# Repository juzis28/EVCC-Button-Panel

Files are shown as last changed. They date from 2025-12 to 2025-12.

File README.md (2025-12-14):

# KEBA EVCC Panel - ESP32 Control System





ESP32-based control panel for managing **EVCC** (Electric Vehicle Charge Controller) charging modes through **Home Assistant**. Physical buttons with LED indicators allow easy mode switching, while a separate status LED panel shows system health.

## ⚠️ Disclaimer

**This project is for personal use and educational purposes only.**

The author assumes no responsibility for any damage, malfunction, or issues arising from the use of this project. Use at your own risk. This documentation is provided "as is" for informational purposes only. Always consult qualified professionals when working with electrical systems and EV charging equipment.

### 🔄 Bidirectional Synchronization

The panel is **fully synchronized** with EVCC and Home Assistant - changes work **in both directions**:
- Press a physical button → EVCC mode changes → Home Assistant updates
- Change mode in Home Assistant → EVCC updates → Panel LED reflects new mode
- Change mode in EVCC web UI → Home Assistant syncs → Panel LED updates automatically

This ensures the panel always shows the **current active mode**, regardless of where the change was initiated.

## 🎯 Project Background

This project was developed for personal use with the following setup:

**EV Charging Station:**
- **KEBA KeContact P30 x-series** wallbox
- Part of **SolarEdge** ecosystem (with SolarEdge inverter)
- Should also be compatible with other original or rebranded KEBA P30 x-series charging stations

**Software Stack:**
| Component | Platform |
|---|---|
| **EVCC** | Proxmox LXC Container |
| **Home Assistant** | Proxmox Virtual Machine |
| **EVCC Integration** | Home Assistant HACS |
| **ESPHome** | Proxmox LXC Container (or local installation) |

## ✨ Features

| Feature | Description |
|---|---|
| **4 Charging Modes** | OFF, SOLAR (PV), MIN+PV, FAST (NOW) |
| **Physical Buttons** | Momentary buttons with integrated LED indicators |
| **Status LED Panel** | 4-LED panel (D1-D4) showing Power, HA, WiFi, EVCC status |
| **Bidirectional Sync** | Panel ↔ Home Assistant ↔ EVCC fully synchronized |
| **Error Mode** | All LEDs blink when WiFi/HA connection lost |
| **5s Restart** | Hold OFF button for 5 seconds to restart ESP32 |
| **Night Mode** | Disable button LEDs via Home Assistant boolean |
| **Multi-Press Protection** | Prevents conflicts from simultaneous button presses |

## 🔧 Hardware

### Assembled Project

The panel features a **3D printed enclosure** mounted on top of the KEBA KeContact P30 charger:

<p align="center">
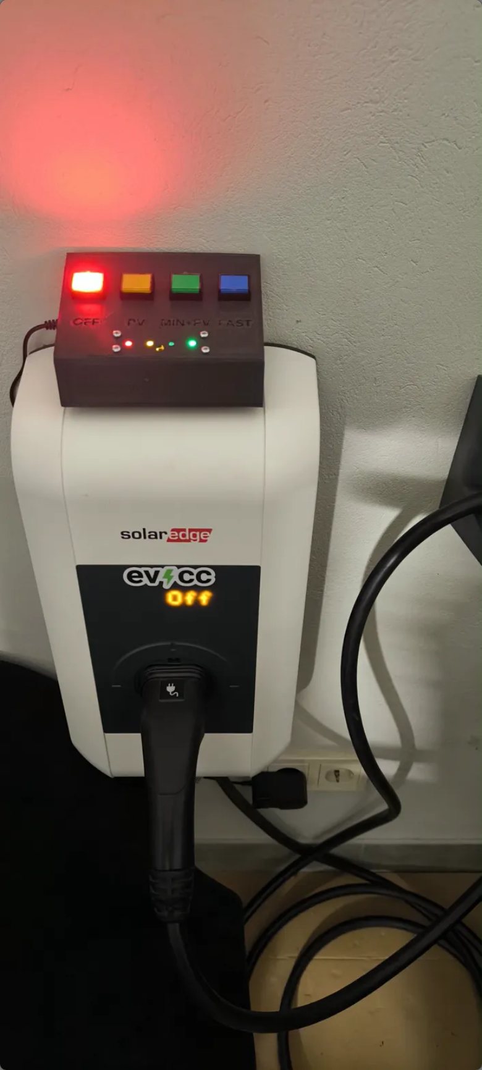
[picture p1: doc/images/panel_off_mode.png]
OFF Mode
  
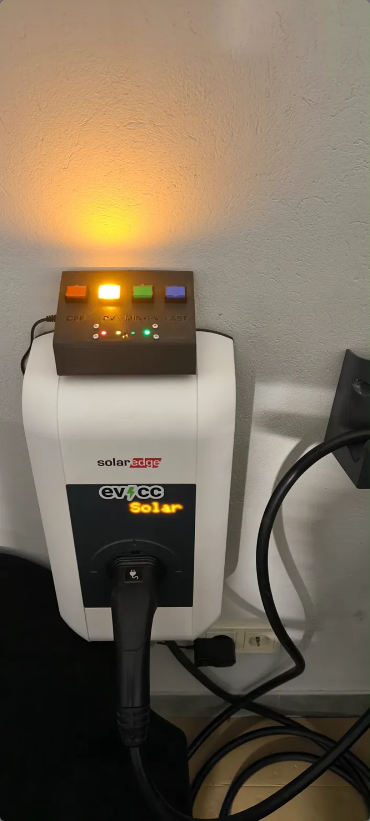
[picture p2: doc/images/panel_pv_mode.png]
PV Mode
  
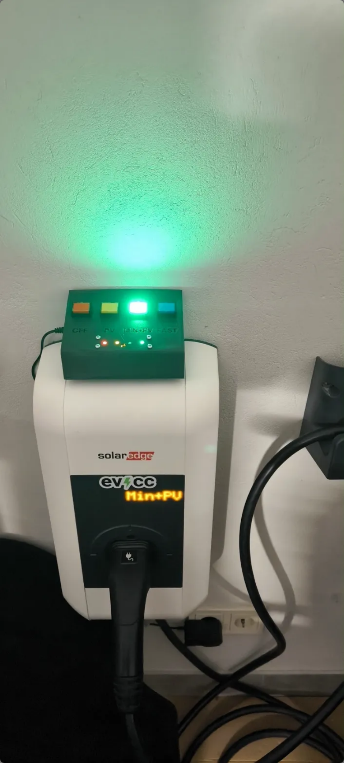
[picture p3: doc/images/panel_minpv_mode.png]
MIN+PV Mode
  
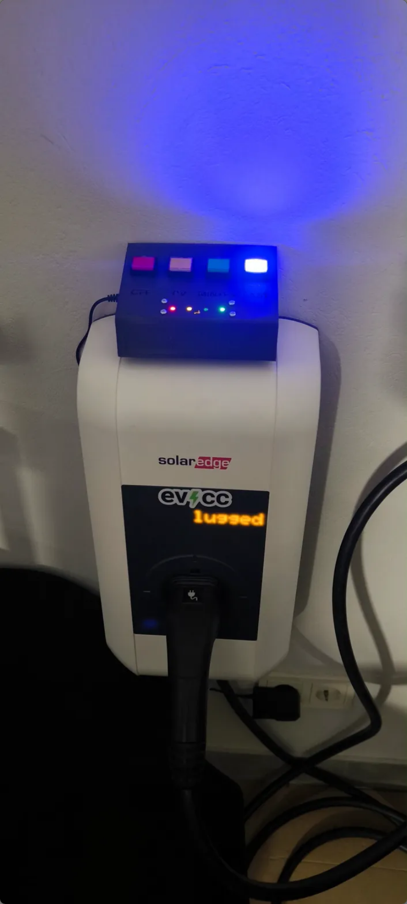
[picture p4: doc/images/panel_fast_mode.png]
FAST Mode
    
</p>

**Visible elements:**
- 4 LED push buttons (OFF, PV, MIN+PV, FAST) with mode labels
- Status LED panel (D1-D4) showing Power, HA, WiFi, EVCC status
- 3D printed enclosure with integrated cable management
- KEBA KeContact P30 x-series charger (SolarEdge branded)

### Main Components

| Component | Description | Link |
|---|---|---|
| **ESP32 Board** | ESP32_Relay_X4_V1.1 (LC Technology) | [AliExpress](https://www.aliexpress.com/item/1005008762604101.html) |
| **LED Buttons** | 12V LED Momentary Push Buttons AL6-M (4 colors) (COM-NO contacts required) | [AliExpress](https://www.aliexpress.com/item/1005007250758674.html) |
| **Status LED Panel** | ST-009 4-Bit Indicator Light Module (DC 3.3-5V) | [AliExpress](https://www.aliexpress.com/item/1005009691105445.html) |
| **DC Power Socket** | 5.5mm x 2.5mm Female Panel Mount Connector | [AliExpress](https://www.aliexpress.com/item/1005006755624202.html) |
| **Power Supply** | 12V 2A AC/DC Adapter (5.5mm x 2.5mm plug) | [AliExpress](https://www.aliexpress.com/item/1005007286854242.html) |

### Component Photos

<p align="center">
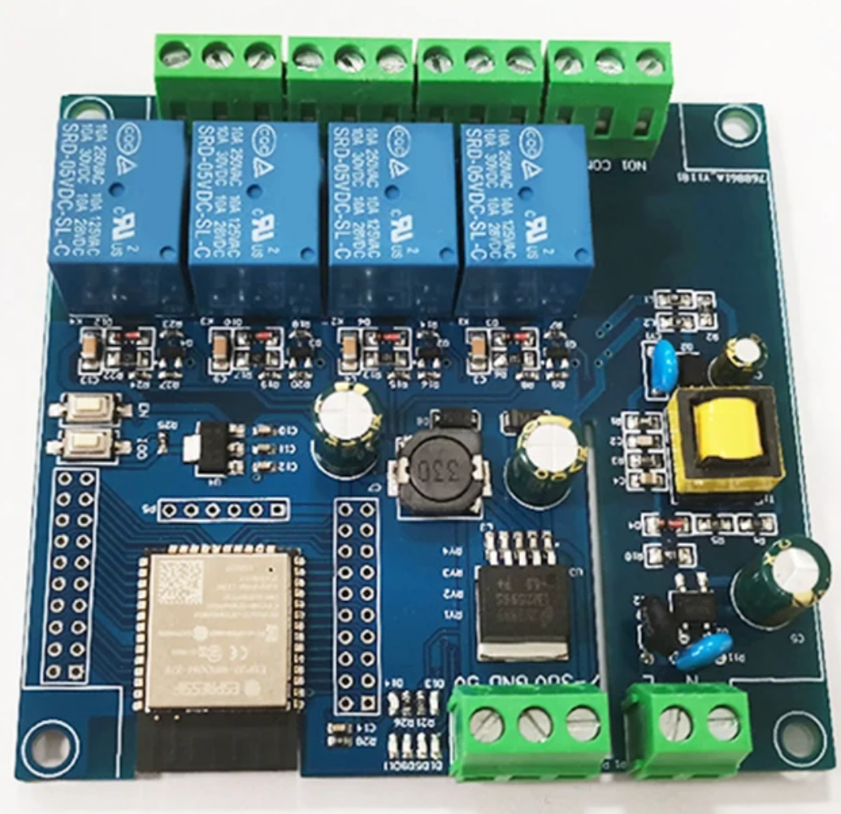
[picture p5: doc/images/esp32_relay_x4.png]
ESP32 Relay X4 Board
  
  <br><em>ESP32_Relay_X4_V1.1 Board</em>
</p>

<p align="center">
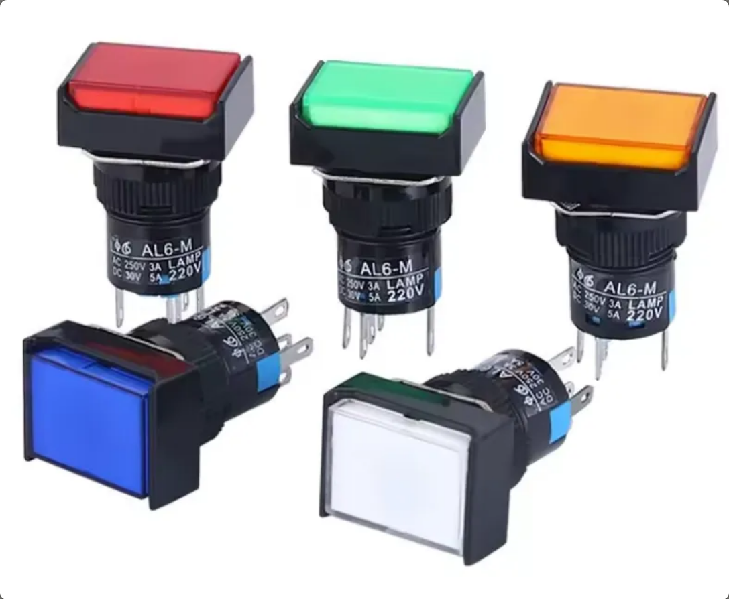
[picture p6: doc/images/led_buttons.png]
LED Push Buttons
  
  <br><em>12V LED Momentary Push Buttons (AL6-M)</em>
</p>

<p align="center">
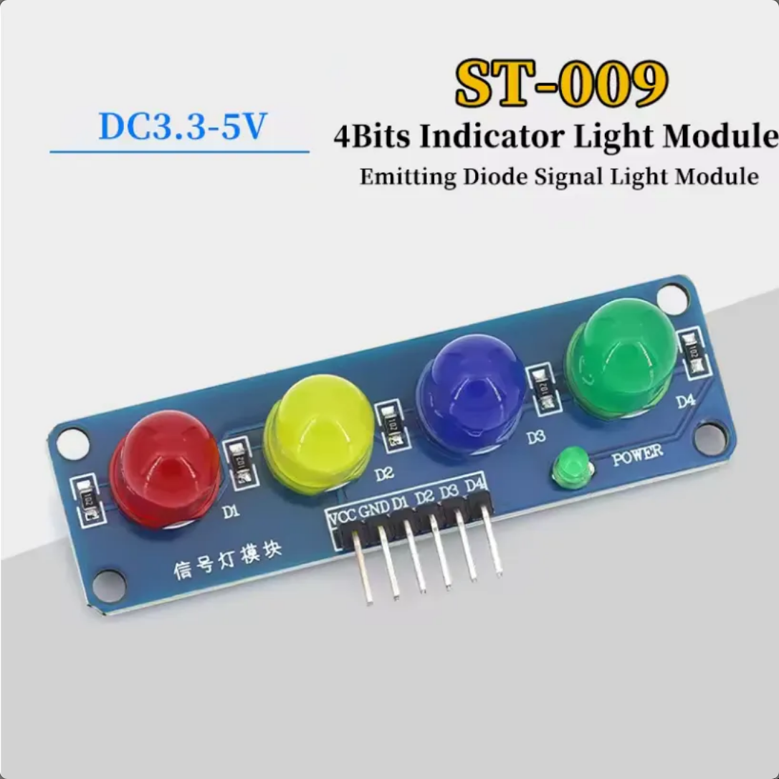
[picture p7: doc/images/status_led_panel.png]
Status LED Panel
  
  <br><em>ST-009 4-Bit Status LED Indicator Module</em>
</p>

### Specifications

- **ESP32 Board:** ESP32_Relay_X4_V1.1 with 4x NO relay contacts, 12V coil, ESP32-WROOM-32E module
- **LED Buttons:** 12V NO momentary push buttons (AL6-M type) with integrated LEDs
  - Button 1: **Red** (OFF)
  - Button 2: **Green** (SOLAR/PV)
  - Button 3: **Yellow/Orange** (MIN+PV)
  - Button 4: **Blue** (FAST/NOW)
- **Status LED Panel:** ST-009 4-Bit module (DC 3.3-5V, Common Anode/Active LOW, D1-D4 labels)
- **DC Power Socket:** 5.5mm x 2.5mm female panel mount connector for 12V input
- **Power Supply:** 12V 2A AC/DC adapter with 5.5mm x 2.5mm barrel plug

### 3D Printed Enclosure

The project includes a custom 3D printed enclosure designed to mount on top of the KEBA charger:
- Holds 4 LED push buttons in a row
- Integrated status LED panel mounting
- Cable management channels
- DC power jack mounting hole

*openSCAD scripts and STL (to be added on request) files available in the [`3d-print`](3d-print) folder*

## 📌 GPIO Pinout

### Relay Outputs (Button LEDs)
| GPIO | Relay | Button | Function | LED Color |
|---|---|---|---|---|
| GPIO32 | Relay 1 | Button 4 | FAST (NOW) | Blue |
| GPIO33 | Relay 2 | Button 3 | MIN+PV | Yellow |
| GPIO25 | Relay 3 | Button 2 | SOLAR (PV) | Green |
| GPIO26 | Relay 4 | Button 1 | OFF | Red |

### Button Inputs
| GPIO | Button | Function | Special |
|---|---|---|---|
| GPIO12 | Button 1 | OFF | Hold 5s = Restart |
| GPIO13 | Button 2 | SOLAR (PV) | - |
| GPIO14 | Button 3 | MIN+PV | - |
| GPIO27 | Button 4 | FAST (NOW) | - |

### Status LED Panel (Active LOW)
| GPIO | LED | Wire | Indication |
|---|-----|---|---|
| GPIO16 | D1 | Pink | Power - Always ON |
| GPIO17 | D2 | Green | HA Connected |
| GPIO18 | D3 | Cyan | WiFi Connected |
| GPIO19 | D4 | Purple | EVCC Entity Received |

**Power from P5 (Programming Header):**
- VCC (5V) ← P5 Pin 1
- GND ← P5 Pin 4 or 5

## 🔌 Wiring

```
+12V Rail (P2) ──────┬──────┬──────┬──────┐
                     │      │      │      │
                    COM    COM    COM    COM
                   [R1]   [R2]   [R3]   [R4]
                    NO     NO     NO     NO
                     │      │      │      │
                   LED+   LED+   LED+   LED+
                  [Btn4] [Btn3] [Btn2] [Btn1]
                   LED-   LED-   LED-   LED-
                     │      │      │      │
GND Rail (P2) ──────┴──────┴──────┴──────┘

Button NO pins → ESP32 GPIOs (12, 13, 14, 27)
Status LEDs → ESP32 GPIOs (16, 17, 18, 19) + P5 power
```
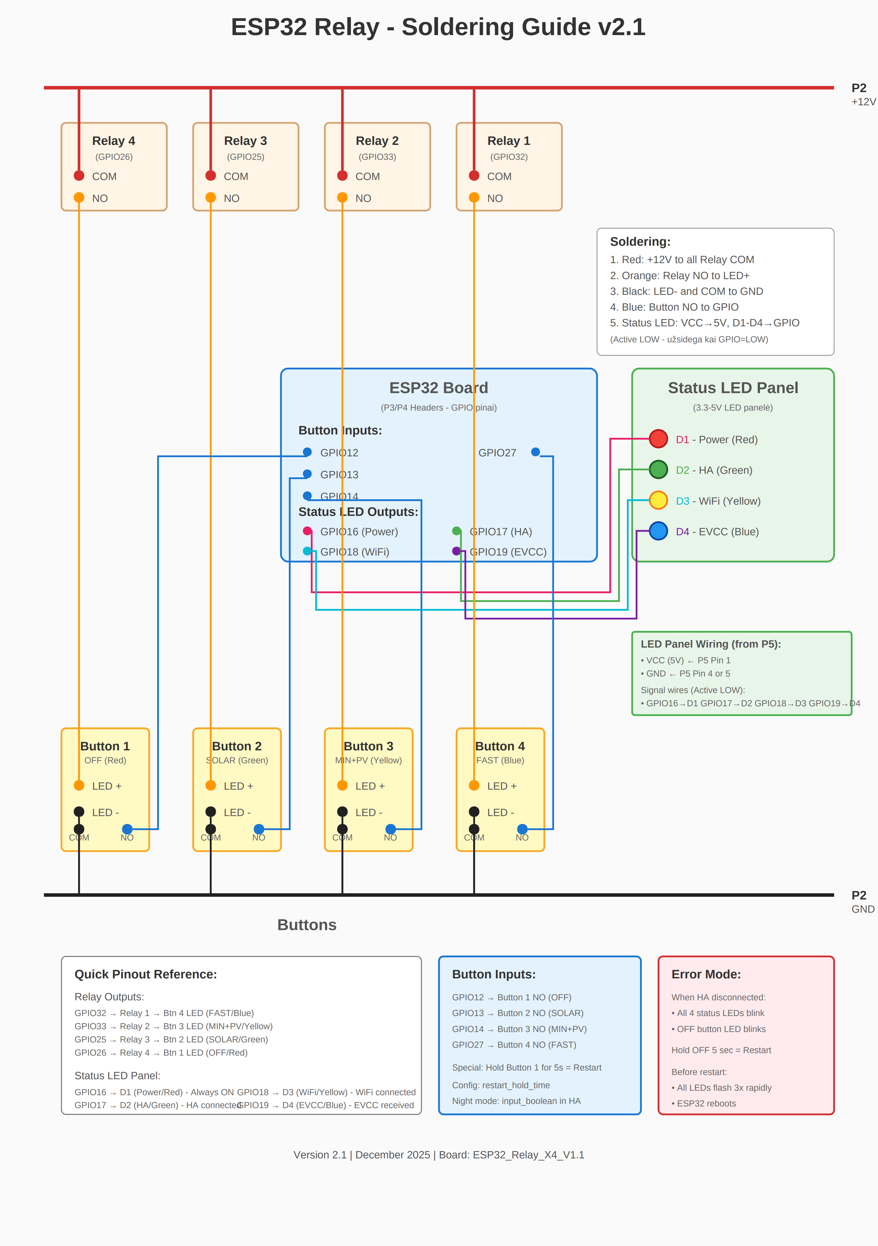
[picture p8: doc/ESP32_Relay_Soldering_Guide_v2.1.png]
Wiring Schematic


## ⚙️ Configuration

### YAML Substitutions
```yaml
substitutions:
  mode_off: "off"
  mode_solar: "pv"
  mode_min_solar: "minpv"
  mode_fast: "now"
  restart_hold_time: "5000ms"
  error_blink_interval: "500ms"
  error_blink_button_led: "true"
```

### Home Assistant Required Entity
```
select.evcc_ev_charger_mode
```

### Optional: Night Mode
Create `input_boolean` in HA to disable button LEDs:
```yaml
input_boolean:
  keba_panel_disable_leds:
    name: "KEBA Panel - Disable Button LEDs"
    icon: mdi:led-off
```

Night mode automation example:
```yaml
automation:
  - alias: "KEBA Panel Night Mode ON"
    trigger:
      - platform: time
        at: "22:00:00"
    action:
      - service: input_boolean.turn_on
        entity_id: input_boolean.keba_panel_disable_leds

  - alias: "KEBA Panel Night Mode OFF"
    trigger:
      - platform: time
        at: "07:00:00"
    action:
      - service: input_boolean.turn_off
        entity_id: input_boolean.keba_panel_disable_leds
```

## 🚀 Installation

1. **Create `secrets.yaml`:**
   ```yaml
   wifi_ssid: "Your_WiFi"
   wifi_password: "Your_Password"
   ap_password: "Fallback_AP_Password"
   ```

2. **Compile & Upload:**
   ```bash
   esphome compile keba-evcc-panel-v2.1.yaml
   esphome upload keba-evcc-panel-v2.1.yaml
   ```

3. **Home Assistant Setup:**
   - Device auto-discovered via ESPHome integration
   - Enable **"Allow service calls"** in device settings
   - Optionally create `input_boolean.keba_panel_disable_leds`

## 🚨 Error Mode

**Triggers:**
- WiFi connection lost
- Home Assistant API disconnected
- 15 seconds after boot without HA connection

**Indicators:**
- All 4 status LEDs (D1-D4) blink synchronously
- OFF button LED blinks (configurable)
- 500ms ON/OFF interval

**Recovery:**
- **Automatic:** When HA reconnects
- **Manual:** Hold OFF button for 5 seconds → 3x rapid flash → ESP32 reboots

## 📁 Project Files

| File | Description |
|---|---|
| `keba-evcc-panel-v2.1.yaml` | ESPHome configuration |
| `doc/ESP32_Relay_Soldering_Guide_v2.1.pdf` | Wiring schematic |
| `doc/KEBA_EVCC_Panel_Manual.pdf` | Complete documentation |

## 🔗 Resources

- [ESPHome Documentation](https://esphome.io/)
- [Home Assistant ESPHome Integration](https://www.home-assistant.io/integrations/esphome/)
- [EVCC Documentation](https://docs.evcc.io/)
- [ESP32_Relay_X4 on ESPHome Devices](https://devices.esphome.io/devices/esp32-relay-x4/)

## 📄 License & Disclaimer

**MIT License** - Free to use and modify.

This project is intended for **personal and educational purposes only**. The author provides this documentation "as is" without any warranties, express or implied. The author shall not be held liable for any damages, injuries, or losses resulting from the use or misuse of this project.

**By using this project, you acknowledge that:**
- You are solely responsible for your own safety
- Working with electrical systems requires proper knowledge and precautions
- EV charging equipment should be installed and maintained by qualified professionals
- You use this information at your own risk

---

**Version 2.1** | December 2025 | Board: ESP32_Relay_X4_V1.1

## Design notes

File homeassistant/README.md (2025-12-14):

# KEBA Wallbox Display Controller

Home Assistant configuration package for intelligent KEBA EV wallbox display management with EVCC integration.

## Features

- **Real-time power display** during charging (e.g., "11.2kW")
- **Animated status messages** with cycling display
- **Automatic LED control** based on connection state
- **Mode change notifications** (Solar, Min+PV, Fast, Off)
- **Energy consumption tracking** sensors

## Prerequisites

- Home Assistant installed and running
- EVCC integration configured with your KEBA wallbox
- `notify.wallbox` service configured for KEBA display

### Required EVCC Entities

| Entity ID | Description |
|---|---|
| `sensor.evcc_ev_charger_charge_power` | Current charging power in kW |
| `binary_sensor.evcc_ev_charger_connected` | EV connection status (on/off) |
| `select.evcc_ev_charger_mode` | Charging mode (off, pv, minpv, now) |
| `sensor.evcc_ev_charger_vehicle_odometer` | Vehicle odometer reading (km) |
| `sensor.evcc_stat_total_charged_kwh` | Total energy charged (kWh) |

## Installation

1. Copy `keba_evcc.yaml` to your Home Assistant packages directory:
   ```
   /config/packages/keba_evcc.yaml
   ```

2. Ensure packages are enabled in your `configuration.yaml`:
   ```yaml
   homeassistant:
     packages: !include_dir_named packages
   ```

3. Restart Home Assistant

4. Verify all automations are enabled in **Settings → Automations**

## Display States

The display cycles between two messages on a 12-second loop (9s primary, 3s secondary):

| State | Primary (9s) | Secondary (3s) |
|---|---|---|
| Charging | Power value (e.g., "11.2kW") | "Charging..." |
| Not connected | "Unplugged" | (empty) |
| Connected, mode off | "Standby" | "Plugged in" |
| Connected, waiting | Mode name (Solar/Min+PV/Fast) | "Waiting..." |

## Components

### Automations

| Automation | Function |
|---|---|
| `KEBA Display - Main loop` | Core display controller (runs every 3s) |
| `KEBA Display - Realtime power update` | Immediate update on power change |
| `KEBA Display - Show mode when changed` | Shows new mode for 12 seconds |
| `KEBA Display - Push updates to wallbox` | Sends text to KEBA via notify.wallbox |
| `KEBA Panel - Enable LEDs when EV connected` | Activates LEDs on vehicle connect |
| `KEBA Panel - Disable LEDs when EV disconnected` | Deactivates LEDs after 5 min |
| `KEBA Display - Reset text on disconnect` | Clears display after 5 min |

## Customization

### Changing Display Messages

Edit the `keba_display_main_loop` automation. Find the relevant state section and modify the `value` template.

### Adjusting Timing

| Setting | Location | Default |
|---|---|---|
| Main loop interval | `seconds: "/3"` | 3 seconds |
| Display cycle ratio | `cycle < 9` condition | 75% primary |
| LED disable delay | `for: "00:05:00"` in disconnect triggers | 5 minutes |
| Mode display duration | `count: 6` and `delay` in mode change automation | 12 seconds |

## Troubleshooting

### Known Issues

#### "Cannot read properties of undefined" Error

This error appears in automation traces for `time_pattern` triggers. This is a **Home Assistant UI bug**, not a configuration problem. The automation executes correctly despite the error message.

### Verification Steps

1. Go to **Developer Tools → States**
2. Search for `input_text.keba_display_text`
3. Verify the value changes every 3 seconds
4. Check wallbox display shows corresponding text

### Common Problems

| Problem | Solution |
|---|---|
| Display not updating | Check if automation is enabled. Verify `notify.wallbox` service is configured. |
| Wrong power values | Verify `sensor.evcc_ev_charger_charge_power` entity exists and has correct values. |
| Mode not showing | Check `select.evcc_ev_charger_mode` entity. Ensure EVCC integration is working. |
| LEDs not turning on/off | Verify `input_boolean.keba_panel_disable_leds` is linked to your wallbox LED control. |

## License

MIT License - Feel free to use and modify.

## Version

2.0 • December 2025

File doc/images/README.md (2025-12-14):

# Project Images

## Required Images for Documentation

| Filename | Description |
|---|---|
| `panel_off_mode.jpg` | Panel showing OFF mode (Red LED active) |
| `panel_pv_mode.jpg` | Panel showing PV/SOLAR mode (Yellow LED active) |
| `panel_minpv_mode.jpg` | Panel showing MIN+PV mode (Green LED active) |
| `panel_fast_mode.jpg` | Panel showing FAST mode (Blue LED active) |

## Component Images (already included)

| Filename | Description |
|---|---|
| `esp32_relay_x4.png` | ESP32_Relay_X4_V1.1 board diagram |
| `led_buttons.png` | AL6-M LED push buttons |
| `status_led_panel.png` | ST-009 4-bit LED indicator module |
| `dc_power_jack.png` | 5.5mm x 2.5mm DC power jack |

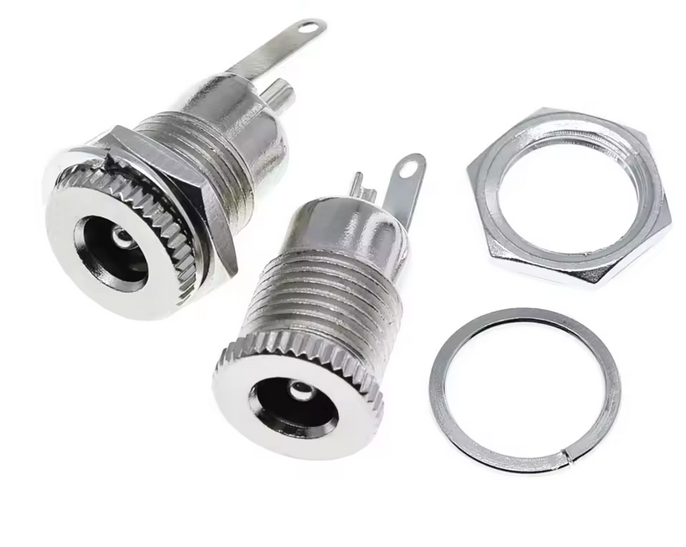
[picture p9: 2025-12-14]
doc/images/dc_power_jack.png

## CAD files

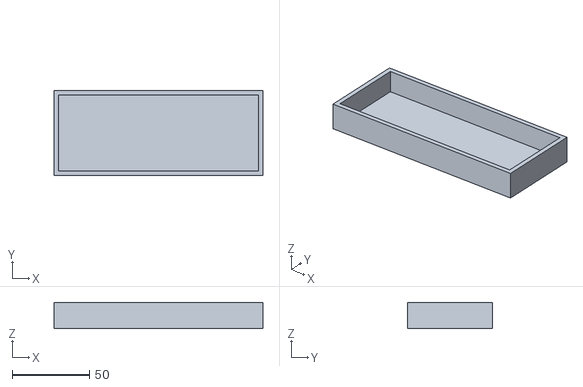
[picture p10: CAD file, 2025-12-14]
3d-print/stl/evcc KEBA shoe 135x55 mm.stl
135.0 x 55.0 x 17.0

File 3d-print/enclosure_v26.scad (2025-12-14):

// ============================================================================
// PART SELECTION - Set to export individual STL files
// ============================================================================
// 0 = show all parts assembled, 1 = body only, 2 = bottom plate, 3 = left side wall, 4 = right side wall, 5 = both side walls, 6 = DEBUG LED holes
part_to_render = 0; 

// ============================================================================
// BUTTON HOLES
// ============================================================================
hole_dia=16.5;
button_num=4;
button_height_auto=1; // 1=auto center vertically, 0=use manual height
button_height_from_bottom=50; // Manual height of button centers from bottom (only if auto=0)
button_height_adjustment=95; // Fine adjustment (+/-) from auto-centered position
button_spacing_auto=1; // 1=auto space buttons evenly, 0=use manual spacing
button_spacing_manual=25; // Manual space between button centers (only if auto=0)
button_margin=20; // Margin from edges when auto-spacing

// ============================================================================
// ENCLOSURE DIMENSIONS
// ============================================================================
enclosure_width=105; // Width (X axis - front to back) - FIXED outer dimension
enclosure_height=70; // Height (Z axis - bottom to top)
enclosure_length_auto=0; // 1=auto calculate from buttons, 0=use custom length
enclosure_length_custom=145; // Custom total length (Y axis) - only used if auto=0
wall_thickness=3;

// ============================================================================
// FRONT PANEL
// ============================================================================
front_flat=35; // Flat section at top of front panel
slope=70; // Angle of front panel

// ============================================================================
// TEXT OPTIONS
// ============================================================================
dotext=1; // 1=yes or 0=no
text_depth=2; // How deep text is engraved
text_size=7; // Text size
text_height=8; // Height of text from bottom (Z position) - for front panel
text_on_slope=1; // 0=text on front vertical panel, 1=text on slope panel with buttons
text_slope_offset=90; // Distance below button center when on slope

// Secondary text (only when text_on_slope=1)
text2_enable=0; // 1=show text2 on front panel when text_on_slope=1
text2_content="evcc"; // Text to display on front panel
text2_size=12; // Size of secondary text
text2_height=10; // Height from bottom
text2_depth=2; // Engraving depth (or raised height if text2_raised=1)
text2_raised=1; // 0=engraved (cut into surface), 1=raised (protrudes from surface)
text2_frame=1; // 1=add rounded frame around text2, 0=no frame
text2_frame_padding=3; // Space between text and frame
text2_frame_radius=3; // Corner rounding radius
text2_frame_thickness=1; // Frame line thickness

// ============================================================================
// LED BOARD OPTIONS (4 digit LED Traffic Light board: 65x19mm, LEDs 10mm, holes 3mm)
// ============================================================================
led_board_enable=1;             // 1=add LED board mounting, 0=no LED board
led_count=4;                    // Number of LEDs (0-4)
led_hole_dia_outside=3;         // Diameter of LED hole on outside (visible)
led_hole_dia_inside=6;          // Diameter of LED hole on inside (larger, for LED fit)
led_hole_depth=2;               // Depth of parabolic transition from inside to outside diameter
led_spacing=15;                 // Space between LED centers
led_board_from_top=36;          // Distance from top of enclosure to board center (base position)
led_board_slide=5;              // Slide whole board along slope: positive=toward buttons, negative=away
led_board_position_y=0;         // Offset from center along Y axis (0=center)
led_vertical_offset=2;          // LED vertical offset from board center (positive=up on board)
led_screw_enable=1;             // 1=add screw holes for LED board, 0=no screw holes
led_screw_hole_dia=3.2;         // M3 screw hole diameter
led_screw_spacing_x=60;         // Horizontal distance between screw holes (board width)
led_screw_spacing_y=15;         // Vertical distance between screw holes (board height)
led_screw_offset_z=0;           // Screw holes Z offset from LED center line

// ============================================================================
// DC POWER SOCKET (5.5x2.5mm jack) on side wall
// ============================================================================
dc_socket_enable=1;             // 1=add DC socket hole, 0=no socket
dc_socket_side=0;               // 0=left side, 1=right side, 2=both sides (viewed from front)
dc_socket_dia=12.5;             // Mounting hole diameter (12.3mm socket + clearance)
dc_socket_from_back=15;         // Distance from back wall (Y position)
dc_socket_from_bottom=12;       // Distance from bottom (Z position)

// ============================================================================
// BOTTOM PLATE OPTIONS
// ============================================================================
bottom_plate_removable=1; // 1=separate bottom plate with screws, 0=integrated bottom
screw_hole_dia=3.2; // Diameter of screw holes (M3 = 3.2mm)
screw_head_dia=6; // Diameter of screw head countersink
screw_head_depth=1.5; // Depth of countersink for screw head
screw_inset_from_edge=10; // Distance of screw holes from edges

// ============================================================================
// SIDE WALLS OPTIONS
// ============================================================================
side_walls_removable=1; // 1=separate left and right side walls, 0=integrated

// Groove for side walls
groove_distance=3;              // Distance from main body edge where groove is cut
groove_depth=1;                 // How deep groove cuts into wall (this determines side wall size)
groove_width_adjustment=1;      // Extra width for clearance (doesn't affect side wall)
groove_depth_adjustment=0.2;    // Extra depth for clearance (doesn't affect side wall)
groove_bottom_extension=1.5;    // How deep groove goes into bottom plate (Z direction)

// Side wall bottom extension (into bottom plate groove)
side_wall_bottom_extension=1.0; // How much side wall extends below Z=0 into bottom plate groove
side_wall_clearance=0.3;        // Clearance around side wall (reduce if too loose, increase if doesn't fit)
bottom_groove_width_adjustment=0.4; // Extra width for bottom plate groove (clearance for side wall)

// ============================================================================
// BOTTOM PLATE LIP (inner L-shape at bottom of front/back walls)
// ============================================================================
lip_enable=1;                   // 1=add lips for bottom plate support
lip_width=7;                    // How far lip extends inward from wall
lip_height=2.5;                 // Height of lip from bottom
lip_inset=2;                    // Distance from groove edge (extra clearance for printing)
lip_screw_dia=2.5;              // Screw hole diameter in lip (for self-tapping screws)
lip_screw_head_dia=5;           // Screw head diameter for countersink
lip_screw_head_depth=1.5;       // Countersink depth in bottom plate
lip_screw_inset=10;             // Distance of screws from lip ends (Y direction) - closer to side walls
lip_cutout_dia=6;               // Cutout diameter in lip for ESP32 mounting access (0=no cutout)

// ============================================================================
// ESP32 RELAY BOARD MOUNTING
// ============================================================================
esp32_board_mount=1; // 1=add mounting posts for board, 0=no posts
esp32_board_width=93; // Width of ESP32 board (along Y axis)
esp32_board_length=87; // Length of ESP32 board (along X axis)
esp32_mount_hole_dia=3.2; // Mounting hole diameter (M3)
esp32_post_dia=6; // Diameter of mounting posts
esp32_post_height=5; // Height of mounting posts above bottom plate
esp32_board_offset_x=0; // Offset from center in X direction
esp32_board_offset_y=0; // Offset from center in Y direction
esp32_corner_inset=3.5; // Distance of mounting holes from board edges
esp32_post_gusset=1; // 1=add reinforcement gussets to posts, 0=no gussets
esp32_gusset_size=4; // Size of triangular gusset at post base

// ============================================================================
// BUTTON TEXT
// ============================================================================
button_1_text="OFF";
button_2_text="PV";
button_3_text="MIN+PV";
button_4_text="FAST";
button_text = [
   [0, button_1_text],
   [1, button_2_text],
   [2, button_3_text],
   [3, button_4_text],
];
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

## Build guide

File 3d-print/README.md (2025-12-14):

# Parametric Enclosure v26

## KEBA EVCC Panel - ESP32 Control System Enclosure

---

## INTRODUCTION

This enclosure is designed for the **KEBA EVCC Panel** project - an ESP32-based control system for SolarEdge KEBA P30 x-series EV charging stations. The enclosure mounts on top of the charging station and provides a user-friendly interface with arcade-style buttons and LED status indicators.

**Key Features:**
- Sloped front panel for ergonomic button access
- 4 arcade buttons for charging mode selection (OFF, PV, MIN+PV, MAX)
- 4 LED status indicators (Traffic Light style)
- ESP32 8-channel relay board housing
- DC power input jack
- Designed to sit neatly on top of KEBA P30 charging station

The design is **fully parametric** - while currently configured for this specific project, all dimensions can be customized for different buttons, boards, and use cases.
<p align="center">
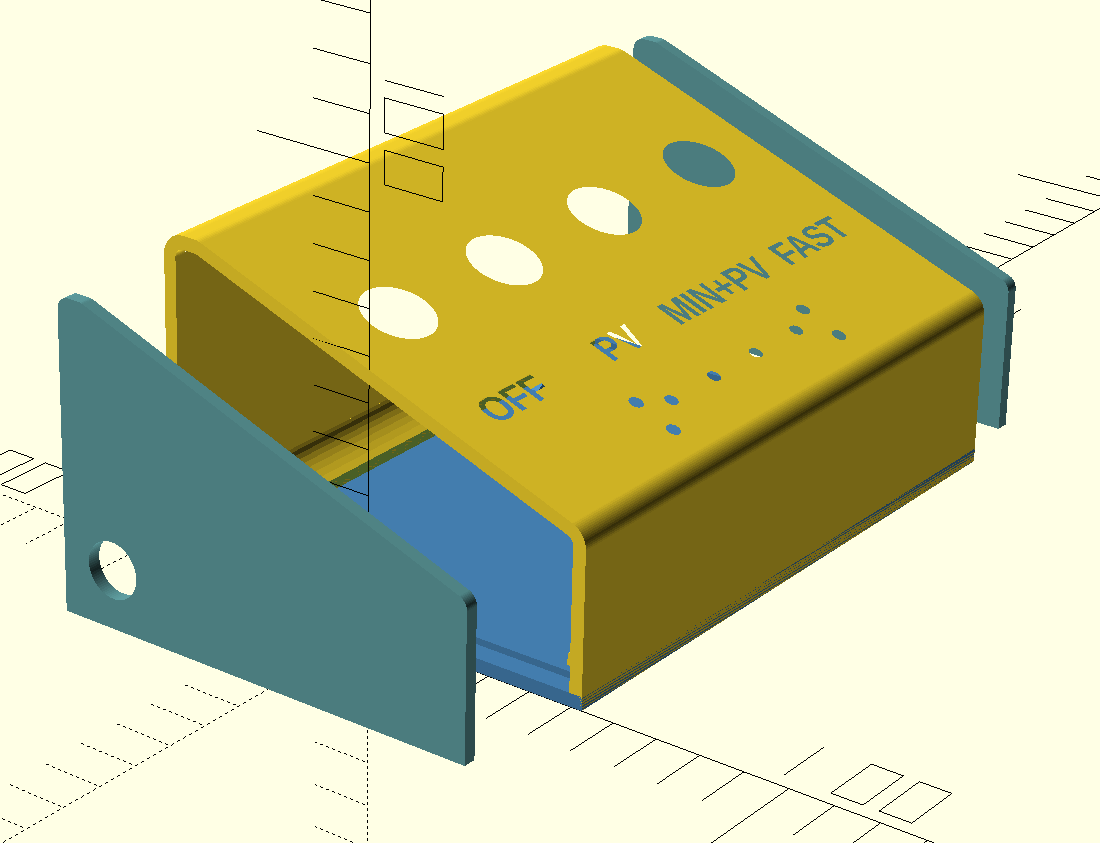
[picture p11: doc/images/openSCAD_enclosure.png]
openSCAD enclosure
  
</p>

---

## OPENSCAD BASICS

### What is OpenSCAD?

OpenSCAD is a free, open-source CAD program for creating 3D models using code. Unlike traditional CAD software, you describe objects programmatically, making it perfect for parametric designs.

### Getting Started

1. **Download OpenSCAD:** [https://openscad.org/downloads.html](https://openscad.org/downloads.html)
2. **Open the .scad file:** File → Open → select `enclosure_v26.scad`
3. **Preview the model:** Press F5 (quick preview) or F6 (full render)
4. **Modify parameters:** Edit values at the top of the file, then press F5 to see changes

### Exporting STL for 3D Printing

1. Set `part_to_render` to the part you want (1-5)
2. Press F6 to render (this may take a moment)
3. File → Export → Export as STL
4. Save with descriptive name (e.g., `enclosure_body.stl`)
5. Repeat for each part

### Tips

- Use F5 for quick preview while adjusting parameters
- Use F6 only when ready to export (slower but accurate)
- Check the Console window for any error messages
- Parameters are at the top of the file with comments explaining each one

---

## 1. OVERVIEW

This parametric enclosure is designed for housing ESP32-based relay control systems with arcade-style push buttons. The design features a sloped front panel for ergonomic button access and LED visibility. All parts are 3D printable without supports when oriented correctly.

---

## 2. TARGET HARDWARE

### Primary Components

| Component | Specifications | Notes |
|---|---|---|
| ESP32 Relay Board | 87 x 93 mm (8-channel) | 4 mounting holes, M3 screws |
| Arcade Push Buttons | 16.5mm mounting hole | Up to 4 buttons supported |
| LED Traffic Light Board | 65 x 19 mm, 4 LEDs | 10mm LEDs, 3mm mounting holes |
| DC Power Jack | 5.5 x 2.5 mm barrel | 12.3mm panel mount hole |

### Recommended Fasteners

| Location | Screw Type | Quantity |
|---|---|---|
| Bottom plate corners | M3 x 8mm | 4 |
| Lip mounting | M2.5 self-tapping | 4 |
| ESP32 board | M3 x 6mm + standoffs | 4 |
| LED board | M3 x 6mm | 4 |

---

## 3. PART SELECTION (`part_to_render`)

Use this parameter to export individual STL files for 3D printing:

| Value | Part | Print Orientation |
|---|---|---|
| 0 | All parts assembled (preview) | N/A - for visualization only |
| 1 | Main body only | Front panel facing down |
| 2 | Bottom plate | Flat side down |
| 3 | Left side wall | Profile face down (nice side) |
| 4 | Right side wall | Profile face down (nice side) |
| 5 | Both side walls | Profile faces down |
| 6 | DEBUG - LED holes | N/A - for debugging |

---

## 4. KEY PARAMETERS

### 4.1 Enclosure Dimensions

| Parameter | Default | Description |
|---|---|---|
| `enclosure_width` | 105 | Width in mm (X axis, front to back) |
| `enclosure_height` | 70 | Height in mm (Z axis) |
| `enclosure_length_custom` | 145 | Length in mm (Y axis) |
| `wall_thickness` | 3 | Wall thickness in mm |
| `front_flat` | 35 | Flat section at top of front panel |
| `slope` | 70 | Angle of sloped front panel (degrees) |

### 4.2 Button Configuration

| Parameter | Default | Description |
|---|---|---|
| `hole_dia` | 16.5 | Button mounting hole diameter (mm) |
| `button_num` | 4 | Number of buttons (1-4) |
| `button_spacing_auto` | 1 | 1=auto space evenly, 0=manual |
| `button_height_auto` | 1 | 1=auto center, 0=manual height |
| `button_height_adjustment` | 95 | Fine adjustment from center |

### 4.3 LED Board Configuration

| Parameter | Default | Description |
|---|---|---|
| `led_board_enable` | 1 | 1=add LED holes, 0=disable |
| `led_count` | 4 | Number of LEDs (0-4) |
| `led_board_from_top` | 36 | Distance from top to board center |
| `led_board_slide` | 5 | Slide along slope (+toward buttons) |
| `led_vertical_offset` | 2 | LED offset from board center |
| `led_screw_enable` | 1 | 1=add screw holes, 0=no screws |

### 4.4 DC Power Socket

| Parameter | Default | Description |
|---|---|---|
| `dc_socket_enable` | 1 | 1=add socket hole, 0=disable |
| `dc_socket_side` | 0 | 0=left, 1=right, 2=both sides |
| `dc_socket_dia` | 12.5 | Mounting hole diameter (mm) |
| `dc_socket_from_back` | 15 | Distance from back wall (mm) |
| `dc_socket_from_bottom` | 12 | Height from bottom (mm) |

### 4.5 ESP32 Board Mounting

| Parameter | Default | Description |
|---|---|---|
| `esp32_board_mount` | 1 | 1=add mounting posts, 0=disable |
| `esp32_board_width` | 93 | Board width in mm (Y axis) |
| `esp32_board_length` | 87 | Board length in mm (X axis) |
| `esp32_post_height` | 5 | Post height above bottom plate |
| `esp32_post_gusset` | 1 | 1=add reinforcement gussets |
| `esp32_board_offset_x/y` | 0 | Offset from center position |

---

## 5. 3D PRINTING GUIDE

### Recommended Print Settings

| Setting | Recommended Value |
|---|---|
| Layer Height | 0.2mm (0.16mm for fine detail) |
| Infill | 20-30% |
| Perimeters | 3 (for strength) |
| Supports | Not required if oriented correctly |
| Material | PLA, PETG, or ABS |
| Bed Adhesion | Brim recommended for side walls |

### Print Orientation per Part

**Main Body (`part_to_render=1`):**
Print with the front panel (sloped side) facing the build plate. This ensures the best surface finish on the visible exterior.

**Bottom Plate (`part_to_render=2`):**
Print flat side down. The mounting posts and gussets will print without supports.

**Side Walls (`part_to_render=3,4,5`):**
Already oriented correctly - the "nice" side (smooth, no layer lines visible) faces down on the print bed and becomes the exterior when assembled.

---

## 6. ASSEMBLY ORDER

1. Install ESP32 relay board onto bottom plate mounting posts with M3 screws
2. Connect all wiring to ESP32 board (power, relays, buttons)
3. Mount DC power jack in side wall (left side by default)
4. Insert side walls into grooves on main body
5. Slide bottom plate into position from below
6. Secure bottom plate with corner screws (M3)
7. Install lip screws (M2.5 self-tapping) through bottom plate into lips
8. Mount LED board from inside using M3 screws
9. Install arcade buttons from front panel

---

## 7. TROUBLESHOOTING

### Side walls don't fit
Adjust `side_wall_clearance` (default 0.3). Increase if too tight, decrease if too loose. Also check `groove_depth` and `groove_width_adjustment`.

### ESP32 posts interfere with lips
The gussets are automatically removed when there's insufficient clearance. If posts still interfere, adjust `esp32_board_offset_x` to move the board, or increase `enclosure_width`.

### LED holes misaligned
Use `part_to_render=6` for debug visualization. Adjust `led_board_from_top`, `led_board_slide`, and `led_vertical_offset` to fine-tune position.

### Buttons too high/low
Set `button_height_auto=0` and manually specify `button_height_from_bottom`, or use `button_height_adjustment` for fine-tuning from auto position.

---

## 8. QUICK REFERENCE

### Enable/Disable Features

| Feature | Parameter | Enable | Disable |
|---|---|---|---|
| LED board holes | `led_board_enable` | 1 | 0 |
| LED screw holes | `led_screw_enable` | 1 | 0 |
| DC power socket | `dc_socket_enable` | 1 | 0 |
| ESP32 mounting | `esp32_board_mount` | 1 | 0 |
| Post gussets | `esp32_post_gusset` | 1 | 0 |
| Bottom plate lip | `lip_enable` | 1 | 0 |
| Button text labels | `dotext` | 1 | 0 |
| Secondary text | `text2_enable` | 1 | 0 |

---

## 9. CUSTOMIZATION

This enclosure is fully parametric - you can adapt it for different projects:

- **Different buttons:** Change `hole_dia` and `button_num`
- **Different ESP32 board:** Adjust `esp32_board_width`, `esp32_board_length`, `esp32_corner_inset`
- **Different LED board:** Modify `led_spacing`, `led_count`, `led_screw_spacing_x/y`
- **Larger/smaller enclosure:** Scale `enclosure_width`, `enclosure_height`, `enclosure_length_custom`
- **Different slope angle:** Adjust `slope` (degrees) and `front_flat`

The current configuration is optimized for:
- SolarEdge KEBA P30 x-series charging station
- ESP32 8-channel relay board (87x93mm)
- 16.5mm arcade push buttons (4x)
- Traffic Light LED board (65x19mm, 4 LEDs)
- 5.5x2.5mm DC barrel jack

---

**Enclosure v26 - KEBA EVCC Panel Project | OpenSCAD Parametric Design | December 2025**

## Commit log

2025-12-14 Create keba-evcc-panel v2.1
    ESP32 yaml code for ESPHome, curent local version v2.1 at release moment. Code dedicated and tuned up for ESP32_Relay_X4_V1.1 (LC Technology, 303E32AC411) ESP32 relay board found on aliexpress ( e.g.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
2025-12-14 Wiring Schematic
    The schematic shows:
    • +12V and GND power rails
    • Relay connections (COM to +12V, NO to Button LED+)
    • Button connections (LED+, LED-, COM, NO)
    • ESP32 GPIO assignments
    • Status LED panel wiring
    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
2025-12-14 Add files via upload
    "shoe" on top of KEBA P30 x-series. v1.
    [evcc KEBA shoe 135x55 mm.stl]
